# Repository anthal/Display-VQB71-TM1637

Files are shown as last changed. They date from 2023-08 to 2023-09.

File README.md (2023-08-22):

# Hardware
Leiterplatte mit 1x TM1637 (Display-Treiber-IC) und 6x VQB71 (rote DDR 7-Segment Displays)

# Anwendungen
## MQTT bzw. Uhrzeit ohne Programmierung
Verwendung der [Tasmota](https://tasmota.github.io/docs/)-Firmware mit ESP8266 oder ESP32 und Anbindung an MQTT.

Tasmota Doku zum TM1637 Display-Treiber: https://tasmota.github.io/docs/TM163x/

### Anschluss bei Verwendung der **WEMOS D1** Hardware
Die 4 Pins der Display Platine können direkt 1:1 mit der **WEMOS D1** Hardware verbunden werden.
 
| WEMOS D1 mini | Display-Platine |
| --- | --- |
| 5V | VCC  |
| G | GND  | 
| D4 | DIO  | 
| D3 | CLK  | 

### Installation und Konfiguration der Firmware:
* Installation der Firmware "Tasmota Display" am einfachsten über den Chrom-Browser und https://tasmota.github.io/install/
* Configuration / Module type (Sonpoff Basic): **Generic (18)**
* D3 GPIO0: TM1637 CLK
* D4 GPIO0: TM1637 DIO

### Konfiguration der Display Parameter über die Console von Tasmota
#### Anzeige der Uhrzeit
Kommandos in der Console zu Anzeige der Uhrzeit:
```
power 1
displaymodel 15
displaywidth 6
displaytype 0
displaymode 1
displaydimmer 7
```

#### Anzeige eines Strings
Kommandos in der Console zu Anzeige eines MQTT Wertes:
```
power 1
displaymodel 15
displaywidth 6
displaytype 0
displaymode 0
displaydimmer 7
displaytext Hallo
```

#### Anzeige eines MQTT Wertes
Kommandos in der Console zu Anzeige eines MQTT Wertes:
```
power 1
displaymodel 15
displaywidth 6
displaytype 0
displaymode 0
displaydimmer 7
```
* ToDo

## Mit Programmierung
### Software
Software für Raspberry Pi Pico in MicroPython

# Bilder

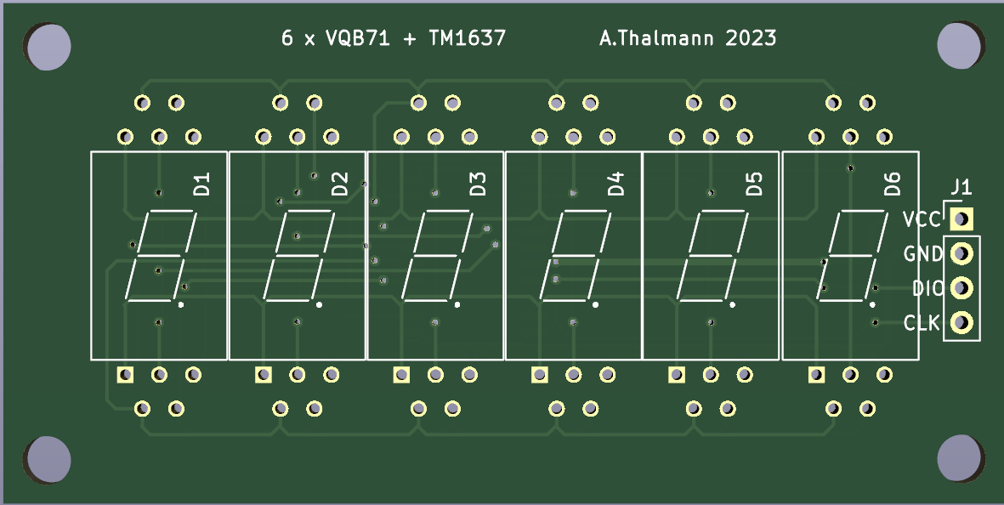
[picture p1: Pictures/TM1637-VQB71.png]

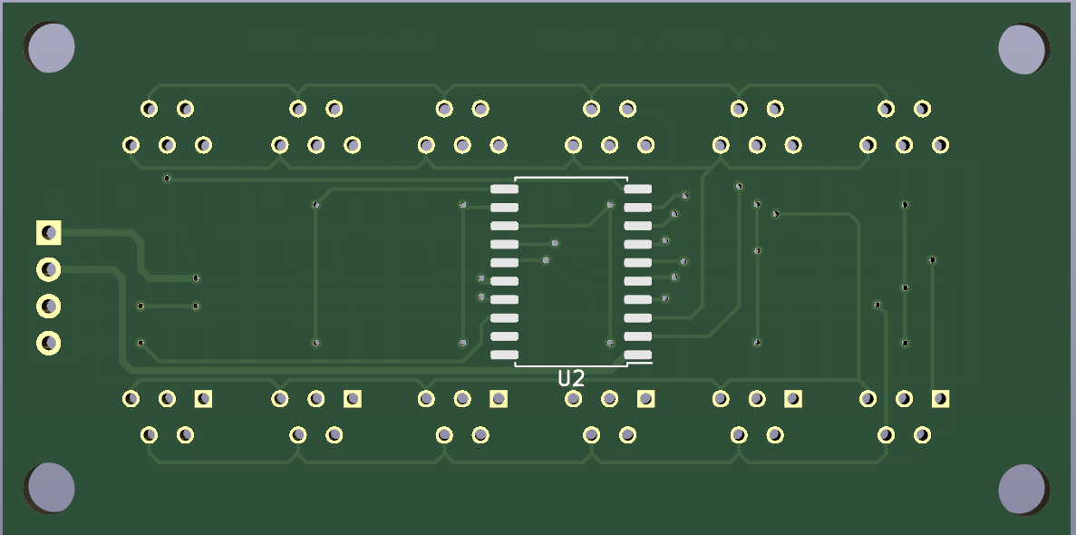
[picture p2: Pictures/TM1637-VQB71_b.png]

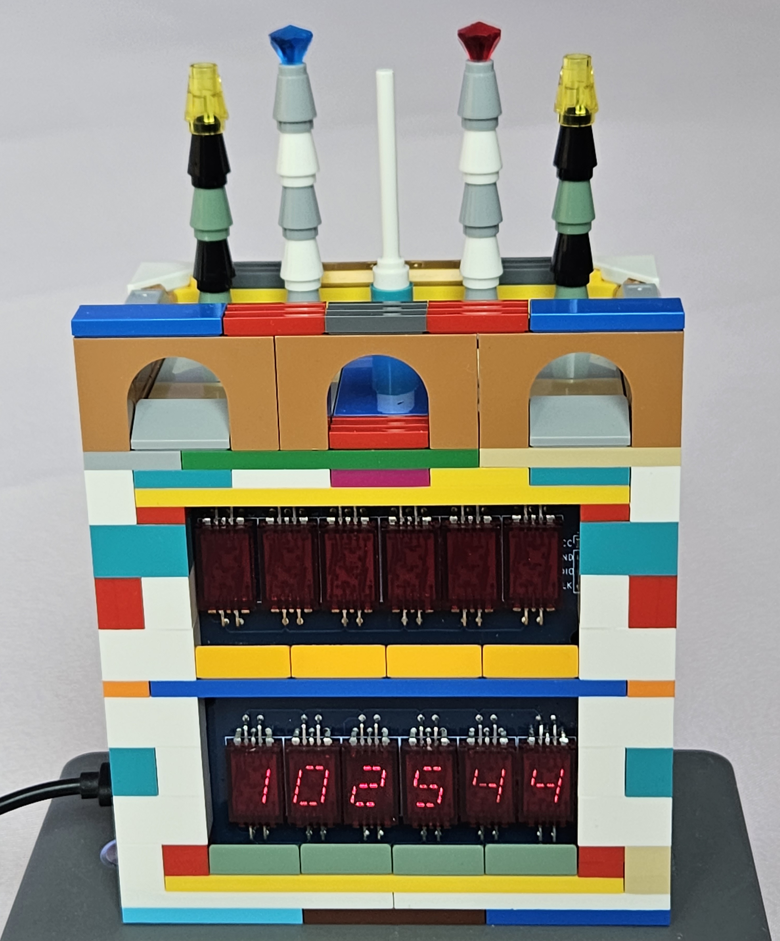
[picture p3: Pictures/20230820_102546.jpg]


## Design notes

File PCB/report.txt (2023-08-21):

Warnung: Breitenkorrektur eingeschränkt.  Für die aktuellen Designregeln muss sich der Breitenkorrekturwert im Bereich [0,000001 mm; 0,199999 mm] befinden.
Plotted to 'D:\Projekte\LED\TM1637-VQB71\TM1637-VQB71-F_Cu.gbr'.
Plotted to 'D:\Projekte\LED\TM1637-VQB71\TM1637-VQB71-B_Cu.gbr'.
Plotted to 'D:\Projekte\LED\TM1637-VQB71\TM1637-VQB71-F_Paste.gbr'.
Plotted to 'D:\Projekte\LED\TM1637-VQB71\TM1637-VQB71-B_Paste.gbr'.
Plotted to 'D:\Projekte\LED\TM1637-VQB71\TM1637-VQB71-F_Silkscreen.gbr'.
Plotted to 'D:\Projekte\LED\TM1637-VQB71\TM1637-VQB71-B_Silkscreen.gbr'.
Plotted to 'D:\Projekte\LED\TM1637-VQB71\TM1637-VQB71-F_Mask.gbr'.
Plotted to 'D:\Projekte\LED\TM1637-VQB71\TM1637-VQB71-B_Mask.gbr'.
Plotted to 'D:\Projekte\LED\TM1637-VQB71\TM1637-VQB71-Edge_Cuts.gbr'.
Hinweis: Fertig.

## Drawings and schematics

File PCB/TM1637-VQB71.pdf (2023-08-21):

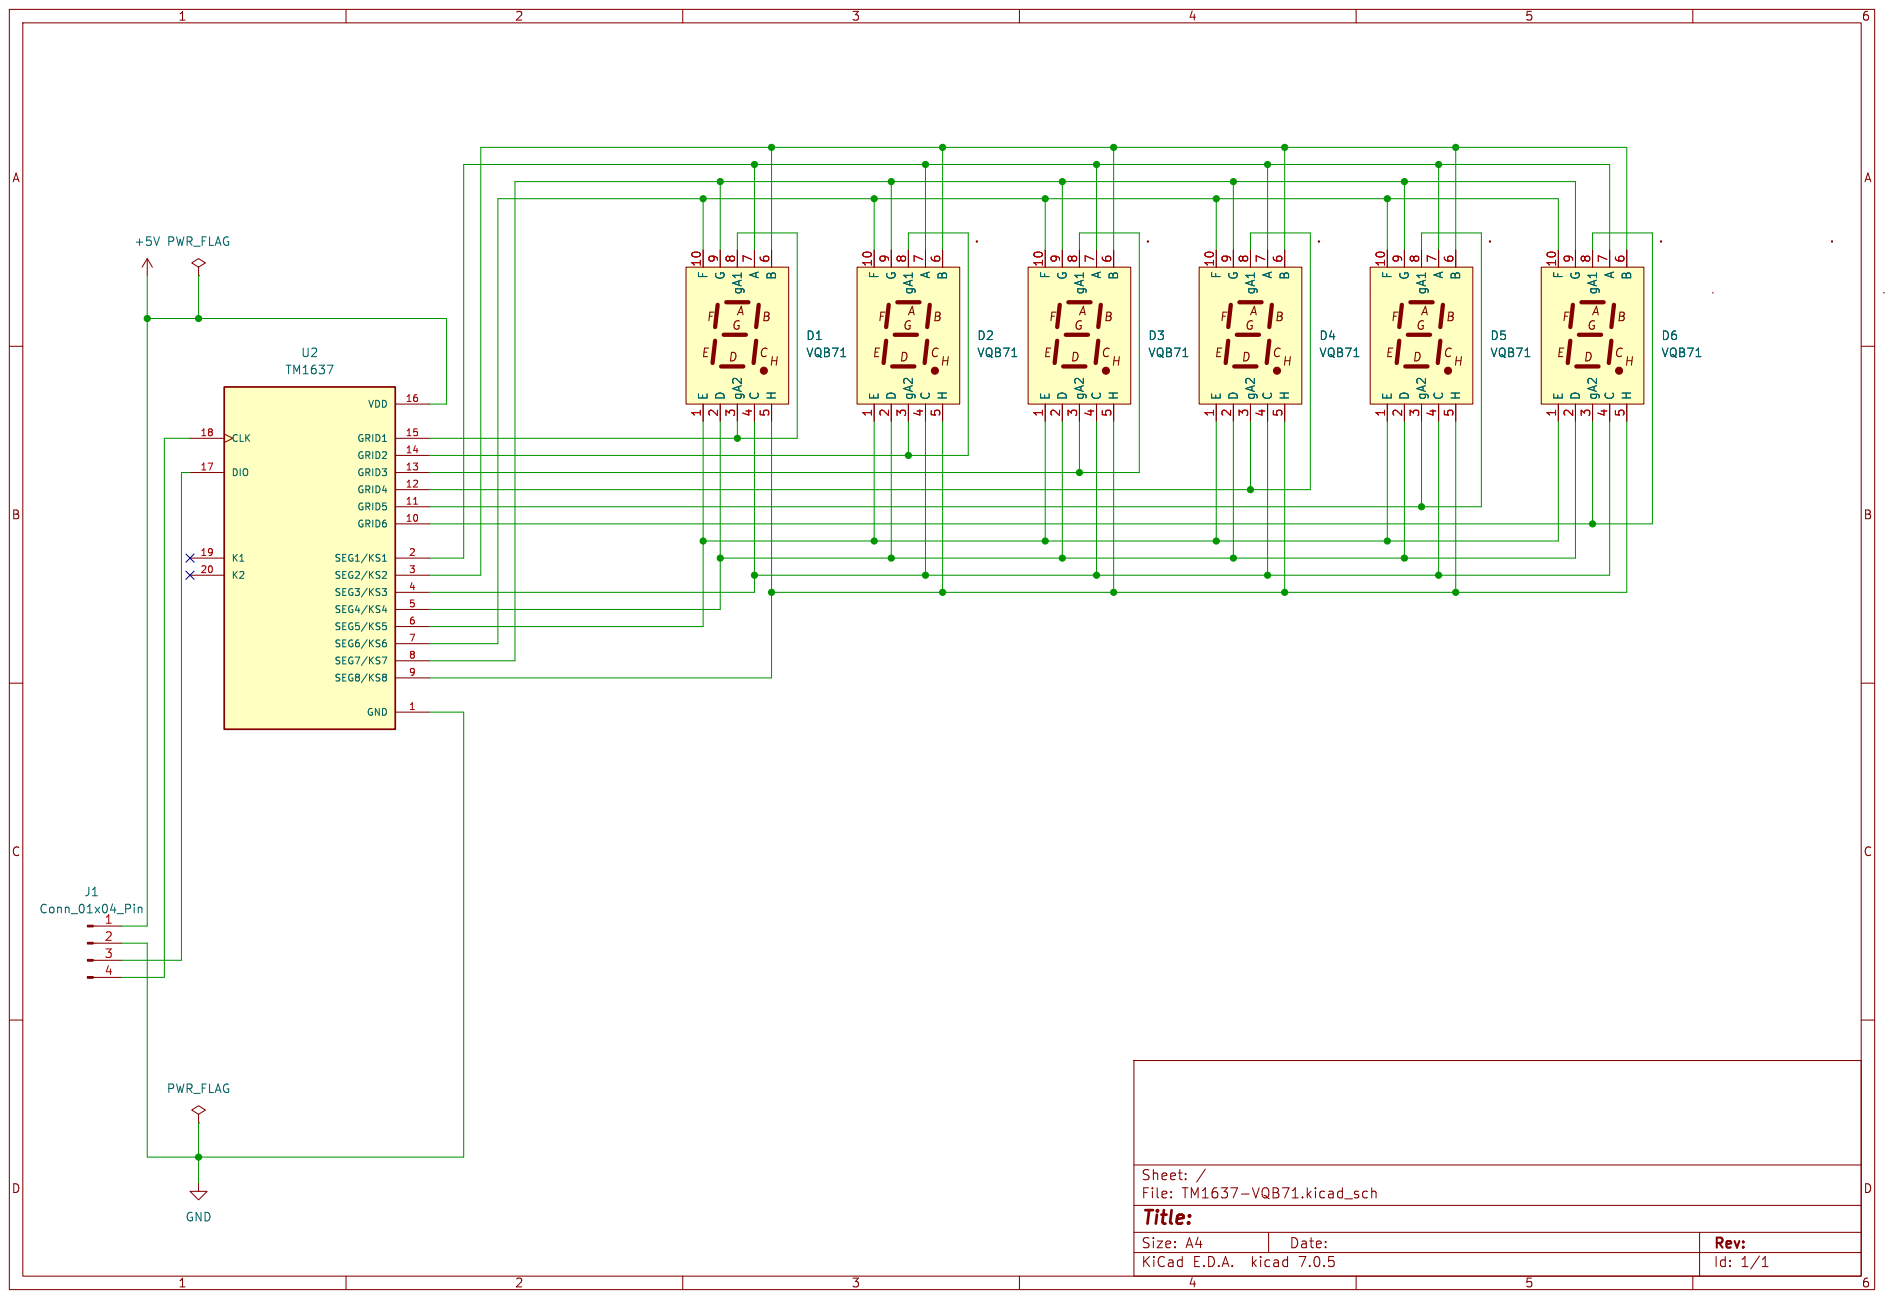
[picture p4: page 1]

Id: 1/1 Title: File: TM1637-VQB71.kicad_sch Sheet: /

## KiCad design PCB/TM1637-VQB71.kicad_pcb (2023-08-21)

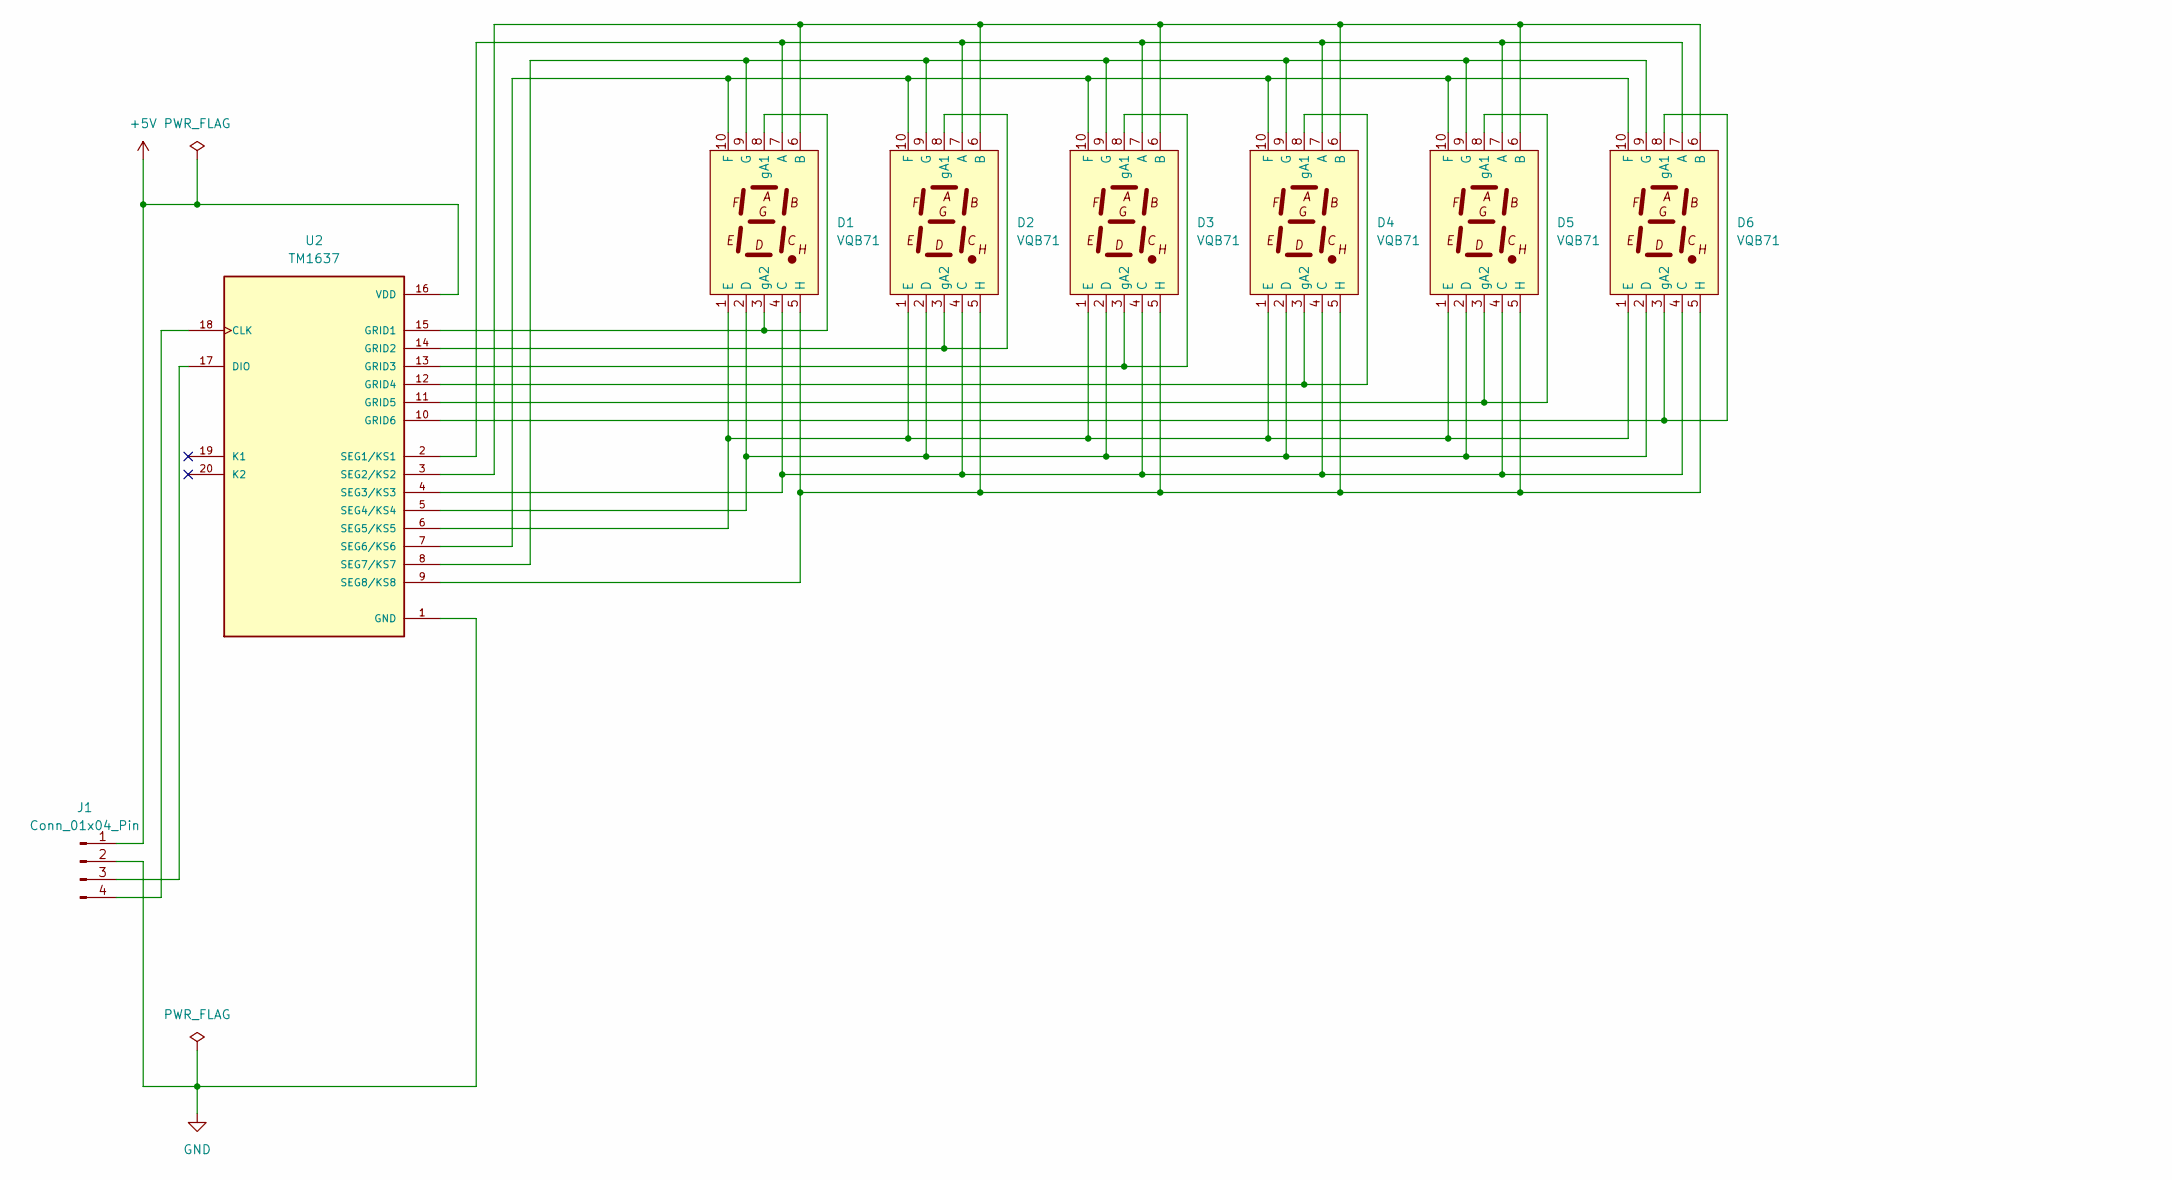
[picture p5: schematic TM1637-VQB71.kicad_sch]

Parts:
D1, D2, D3, D4, D5, D6: VQB71; D_VQB71
J1: Conn_01x04_Pin; PinHeader_1x04_P2.54mm_Vertical
U2: TM1637; SOP-20_7.5x12.8mm_P1.27mm; PARTREV v2.5

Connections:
+5V: J1.1, U2.16 (VDD)
GND: J1.2, U2.1 (GND)
unnamed: D1.7 (A), D2.7 (A), D3.7 (A), D4.7 (A), D5.7 (A), D6.7 (A), U2.2 (SEG1/KS1)
unnamed: D1.6 (B), D2.6 (B), D3.6 (B), D4.6 (B), D5.6 (B), D6.6 (B), U2.3 (SEG2/KS2)
unnamed: D1.4 (C), D2.4 (C), D3.4 (C), D4.4 (C), D5.4 (C), D6.4 (C), U2.4 (SEG3/KS3)
unnamed: D1.2 (D), D2.2 (D), D3.2 (D), D4.2 (D), D5.2 (D), D6.2 (D), U2.5 (SEG4/KS4)
unnamed: D1.1 (E), D2.1 (E), D3.1 (E), D4.1 (E), D5.1 (E), D6.1 (E), U2.6 (SEG5/KS5)
unnamed: D1.10 (F), D2.10 (F), D3.10 (F), D4.10 (F), D5.10 (F), D6.10 (F), U2.7 (SEG6/KS6)
unnamed: D1.9 (G), D2.9 (G), D3.9 (G), D4.9 (G), D5.9 (G), D6.9 (G), U2.8 (SEG7/KS7)
unnamed: D1.5 (H), D2.5 (H), D3.5 (H), D4.5 (H), D5.5 (H), D6.5 (H), U2.9 (SEG8/KS8)
unnamed: D1.3 (gA2), D1.8 (gA1), U2.15 (GRID1)
unnamed: D2.3 (gA2), D2.8 (gA1), U2.14 (GRID2)
unnamed: D3.3 (gA2), D3.8 (gA1), U2.13 (GRID3)
unnamed: D4.3 (gA2), D4.8 (gA1), U2.12 (GRID4)
unnamed: D5.3 (gA2), D5.8 (gA1), U2.11 (GRID5)
unnamed: D6.3 (gA2), D6.8 (gA1), U2.10 (GRID6)
unnamed: J1.3, U2.17 (DIO)
unnamed: J1.4, U2.18 (CLK)

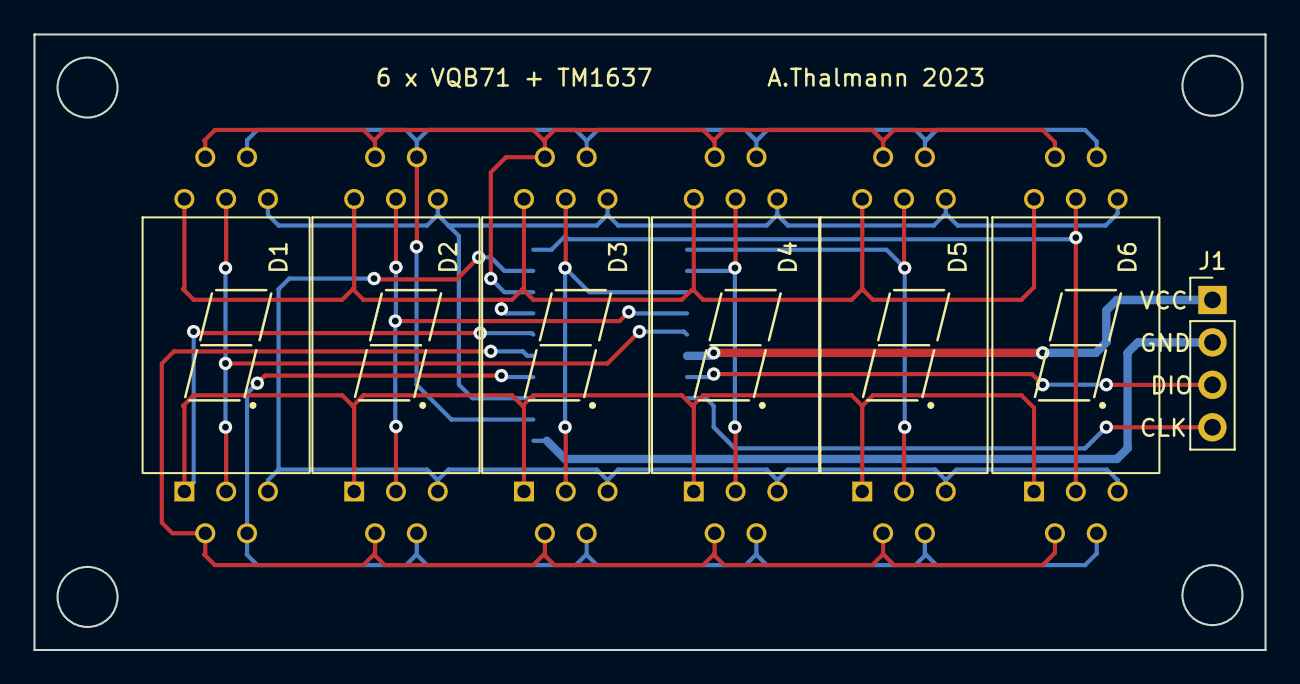
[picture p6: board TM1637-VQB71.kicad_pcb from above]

Board: 2 copper layers, 73.7 x 36.8 mm, 8 parts (1 on the bottom side), 18 nets.

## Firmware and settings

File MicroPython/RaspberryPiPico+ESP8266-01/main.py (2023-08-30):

"""

"""
import uos
import utime
#import machine
import tm1637_6dig

from machine import UART
from machine import Pin
from machine import WDT
from machine import RTC
from machine import Timer
#import micropython

# Winterzeit / Sommerzeit
#GMT_OFFSET = 1 # 1 h (Winterzeit)
GMT_OFFSET = 2 # 2 h (Sommerzeit)

# NTP-Host
#NTP_HOST = 'pool.ntp.org'
NTP_HOST = '192.168.0.1'

# Onboard-LED:
led = Pin(25, Pin.OUT)

class SERIAL():

    def init(self):
        """
        Init
        """
        #self.uart0 = UART(0, baudrate=9600, tx=Pin(0), rx=Pin(1), bits=8, parity=None, stop=1, txbuf=256, flow=0)
        self.uart0 = UART(1, baudrate=9600, tx=Pin(8), rx=Pin(9), bits=8, parity=None, stop=1, txbuf=256, flow=0)
        #self.uart0 = UART(1, baudrate=115200, tx=Pin(8), rx=Pin(9), bits=8, parity=None, stop=1, txbuf=256, flow=0)
        print("Machine:     " + uos.uname()[4])
        print("MicroPython: " + uos.uname()[3])
        #print(micropython.mem_info())
        # all LEDS off
        tm1.write([0, 0, 0, 0, 0 ,0])
        tm2.write([0, 0, 0, 0, 0 ,0])
        tm3.write([0, 0, 0, 0, 0 ,0])


    def send_at_cmd(self, at_cmd, debug=False):
        """
        Sende AT Kommando an GSM-Modul
        """
        txData = b'AT{}\r\n'.format(at_cmd)
        # Sende den Puffer mit Bytes:
        self.uart0.write(txData)
        if debug:
            print("Send: 'AT{}'".format(at_cmd))


    def read_answer(self, line=True):
        """
        Hole Antwort vom GSM-Modul
        
        :line:
        * True - Use of readline from UART
        * False - Use of read one character from UART 
        """
        rx_data_dec_list = []
        rxData = bytes()
        # "any": Anzahl der Bytes im Empfangspuffer:
        #print(self.uart0.any())
        # Für anspruchsvollere Abfragen der verfügbaren Zeichen verwenden Sie select.poll
        while self.uart0.any() > 0:
            #led_blink()
            if line:
                # Hole alle Bytes einer Zeile:
                rxData = self.uart0.readline()
            else:
                # Hole ein Byte:
                rxData = self.uart0.read(1)
            # print(rxData)

            try:
                rx_data_dec = rxData.decode('utf-8')
            except:
                print("Unicode-Error in '{}'".format(rxData))
                rx_data_dec = ""
                # return None

            if line:
                rx_data_dec_list.append(rx_data_dec[:-2])
            else:
                rx_data_dec_list.append(rx_data_dec)

            # Reset Watchdog:
#            wdt.feed()

        #if line:
        #    if rx_data_dec_list:
        #        print(rx_data_dec_list)
        return rx_data_dec_list


    def wait_of_ser_line(self, wait_string, debug=False):
        """
        Warte auf Zeile wait_string vom GSM Modul

        """
        ret_list = self.read_answer()
        if ret_list:
            if debug:
                print("read_answer: " + str(ret_list))
        i = 0
        while (wait_string not in ret_list):
            ret_list = self.read_answer()
            if ret_list:
                if debug:
                    print("read_answer: " + str(ret_list))
            if ret_list and "ERROR" in ret_list:
                return("ERROR")
            #if not ret_list:
            #    return("Keine verwertbare Antwort vom GSM Modul")
            utime.sleep(0.1)
            i += 1
            # print(i)
            led_blink()

            if i > 10:
                if not ret_list:
                    return("Keine Antwort vom ESP-Modul!")
                else:
                    return("'" + wait_string + "' nicht gefunden!")

        return(ret_list)


def led_blink(on_time=0.1):
    led.value(1)
    utime.sleep(on_time)
    led.value(0)


def get_month_num(month):
    if month == "Jan":
        return 1
    if month == "Feb":
        return 2
    if month == "Mar":
        return 3
    if month == "Apr":
        return 4
    if month == "Mai":
        return 5
    if month == "Jun":
        return 6
    if month == "Jul":
        return 7
    if month == "Aug":
        return 8
    if month == "Sep":
        return 9
    if month == "Okt":
        return 10
    if month == "Nov":
        return 11
    if month == "Dec":
        return 12

####################################################################
# MAIN
####################################################################
# Add Objekte:
ser = SERIAL()
rtc = RTC()

tm1 = tm1637_6dig.TM1637(clk=Pin(0), dio=Pin(1))
tm2 = tm1637_6dig.TM1637(clk=Pin(2), dio=Pin(3))
tm3 = tm1637_6dig.TM1637(clk=Pin(4), dio=Pin(5))

ser.init()

tm1.show('000000')
tm2.show('000000')
tm3.show('unsync')

tm1.numbers(0, 0, 0)
tm2.numbers(0, 0, 0)

print("Suche ESP-Modul...")
# Warten nach Kaltstart:
#utime.sleep(6)
# Test Kommunikation zum ESP:
ser.send_at_cmd("")
ret_val = ser.wait_of_ser_line("OK", True)
#print(ret_val)
if "OK" not in ret_val:
    print("ERROR: keine Antwort vom ESP")
else:
    # Reset:
    #ser.send_at_cmd("+RST")
    #ret_val = ser.wait_of_ser_line("OK")
 
    # Versionsabfrage:
    #ser.send_at_cmd("+GMR")
    #ret_val = ser.wait_of_ser_line("OK")

    # Setzen des NTP-Servers:
    ser.send_at_cmd("+CIPSNTPCFG=1,%s,\"%s\"" % (GMT_OFFSET, NTP_HOST))
    ret_val = ser.wait_of_ser_line("OK", True)
    
    # Setzen des Client-Modes:
    ser.send_at_cmd("+CWMODE=1")
    ret_val = ser.wait_of_ser_line("OK", True)

    # Anmelden im WLAN:
    ser.send_at_cmd("+CWJAP=\"anth-0\",\"anthal-17!\"")
    #ret_val = ser.wait_of_ser_line("WIFI", True)
    ret_val = ser.wait_of_ser_line("WIFI DISCONNECT", True)
    utime.sleep(5)
    ret_val = ser.wait_of_ser_line("WIFI CONNECTED", True)

    # Abfrage der IP-Adresse:
    ser.send_at_cmd("+CIPSTA?")
    ret_val = ser.wait_of_ser_line("OK", True)
    # 'AT+CIPSTA?',
    # '+CIPSTA:ip:"192.168.0.129"',
    # '+CIPSTA:gateway:"192.168.0.1"',
    # '+CIPSTA:netmask:"255.255.255.0"',
    # '',
    # 'OK'
    ip = ret_val[1].split('"')[1]
    print()
    print("IP-Adresse: " + ip)
    ip = ip.split(".")
    #print(ip[3])
    #utime.sleep(5)
    while True:
        # Setzen des NTP-Zeitabfrage:
        ser.send_at_cmd("+CIPSNTPTIME?")
        ret_val = ser.wait_of_ser_line("OK")
        timestring = ret_val[1].split(":")
        day = int(timestring[1].split(" ")[2])
        month = timestring[1].split(" ")[1]
        year = int(timestring[3].split(" ")[1])
        hour = int(timestring[1].split(" ")[3])
        minute = int(timestring[2])
        second = int(timestring[3].split(" ")[0])
        month = int(get_month_num(month)) 
        
        print("{0:02}.{1:02}.{2:02}".format(day, month, year-2000), end=' - ')
        print("{0:02}:{1:02}:{2:02}".format(hour, minute, second))
        tm1.numbers(hour, minute, second)
        tm2.numbers(day, month, int(year) - 2000)
        tm3.show('IP ' + ip[3])
        #tm3.show('888888')
        utime.sleep(1)
      

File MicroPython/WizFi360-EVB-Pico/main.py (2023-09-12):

#
import network
import secrets
import utime
import tm1637_6dig

from machine import Pin
from machine import RTC

import uasyncio as asyncio

# Load login data from different file for safety reasons
ssid = secrets.secrets['ssid']
key = secrets.secrets['key']

led0 = machine.Pin(25, machine.Pin.OUT)


def get_month(month_str):
    if month_str == "Jan":
        return "01"
    if month_str == "Feb":
        return "02"
    if month_str == "Mar":
        return "03"
    if month_str == "Apr":
        return "04"    
    if month_str == "May":
        return "05"
    if month_str == "Jun":
        return "06"
    if month_str == "Jul":
        return "07"
    if month_str == "Aug":
        return "08"    
    if month_str == "Sep":
        return "09"
    if month_str == "Oct":
        return "10"
    if month_str == "Nov":
        return "11"
    if month_str == "Dec":
        return "12"    


####################################################################
# MAIN
####################################################################
# Add Objekte:
rtc = RTC()

tm1 = tm1637_6dig.TM1637(clk=Pin(0), dio=Pin(1))
tm2 = tm1637_6dig.TM1637(clk=Pin(2), dio=Pin(3))
tm3 = tm1637_6dig.TM1637(clk=Pin(12), dio=Pin(13))
tm4 = tm1637_6dig.TM1637(clk=Pin(10), dio=Pin(11))
tm5 = tm1637_6dig.TM1637(clk=Pin(8), dio=Pin(9))

#tm1.show('Unsync')
#tm2.show('Unsync')
#tm3.show('unsync')
#tm4.show('unsync')
#tm5.show('unsync')
tm1.show('111111')
tm2.show('222222')
tm3.show('333333')
tm4.show('444444')
tm5.show('555555')

led0.value(0)

wlan = network.WLAN(network.STA)
wlan.active(True)
retval = wlan.connect(ssid, key)
print(retval)

if wlan.isconnected():
    print("WLAN Connected")
    print(wlan.ifconfig())
    cmd = 'CIPSNTPCFG=1,2,'+ secrets.network['ntp-server']
    print(cmd)
    ret_val = wlan.sendATcmd_waitResp(cmd)
    print(ret_val)
    # Warten auf OK:
    while "ERROR" in ret_val:
        ret_val = wlan.sendATcmd_waitResp(cmd)
        print(ret_val)
        utime.sleep(1)

    # Abfrage der aktuellen Zeit per  NTP:
    cmd = 'CIPSNTPTIME?'
    second_old = "0"
    while True: 
        ret_val = wlan.sendATcmd_waitResp(cmd, debug=False)
        time_list1 = str(ret_val).split(" ")
        month = get_month(time_list1[1])
        day = time_list1[2]
        year = time_list1[4][0:4]
        timestr = time_list1[3]
        time_list2 = timestr.split(":")
        hour = time_list2[0]
        minute = time_list2[1]
        second = time_list2[2]
        
        if second != second_old and int(year) > 2022:
        #if second != second_old:
            print("{}.{}.{} {}:{}:{}".format(day, month, year, hour, minute, second))
            second_old = second
            tm1.numbers(int(hour), int(minute), int(second))
            tm2.numbers(int(day), int(month), int(year[2:4]))
            tm3.numbers(int(hour), int(minute), int(second))
            tm4.numbers(int(day), int(month), int(year[2:4]))
            tm5.numbers(int(hour), int(minute), int(second))

            if int(second) % 2 == 0:
                led0.value(1)
            else:
                led0.value(0)
        
        utime.sleep(0.5)

else:
    print("No WLAN Connection!")

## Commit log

2023-08-21 Create PCB
2023-08-21 Add main PCB Files
    [TM1637-VQB71.kicad_pcb, TM1637-VQB71.kicad_sch]
2023-08-21 ADD PCB picture files
2023-08-21 ADD Bilder der fertigen Leiterplatten
2023-09-12 ADD: Initialer Commit für WizFi360-EVB-Pico
